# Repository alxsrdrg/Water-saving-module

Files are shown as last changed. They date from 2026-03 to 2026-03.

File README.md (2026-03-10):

# Water-saving-module
This is the data gatherer for a bigger project that will collect ambient data to save water while watering plants.
Hello, my name is Alexis. I am part of ACOIIN in Chile, and I designed this PCB to save water during the process of watering plants.

Most people don’t know how much water plants actually need to be watered efficiently, so I designed this small ATtiny85-based data gatherer to interface with other modules that will help water plants more efficiently—saving water, saving money, and helping the environment.

To use it you must upload the code to an ATtiny85 connect it to the pcb then upload the recivers code to an arduino with the reciver and watch the serial interface for the data this will be feeded into a algorthm tha will take the best moment for you to water the plants (WIP)

(BOM: https://docs.google.com/spreadsheets/d/1GQ0v_dI7ZX-GIWkH-TXZdrfXvmL1TNvHDqjCibz4H14/edit?usp=sharing)



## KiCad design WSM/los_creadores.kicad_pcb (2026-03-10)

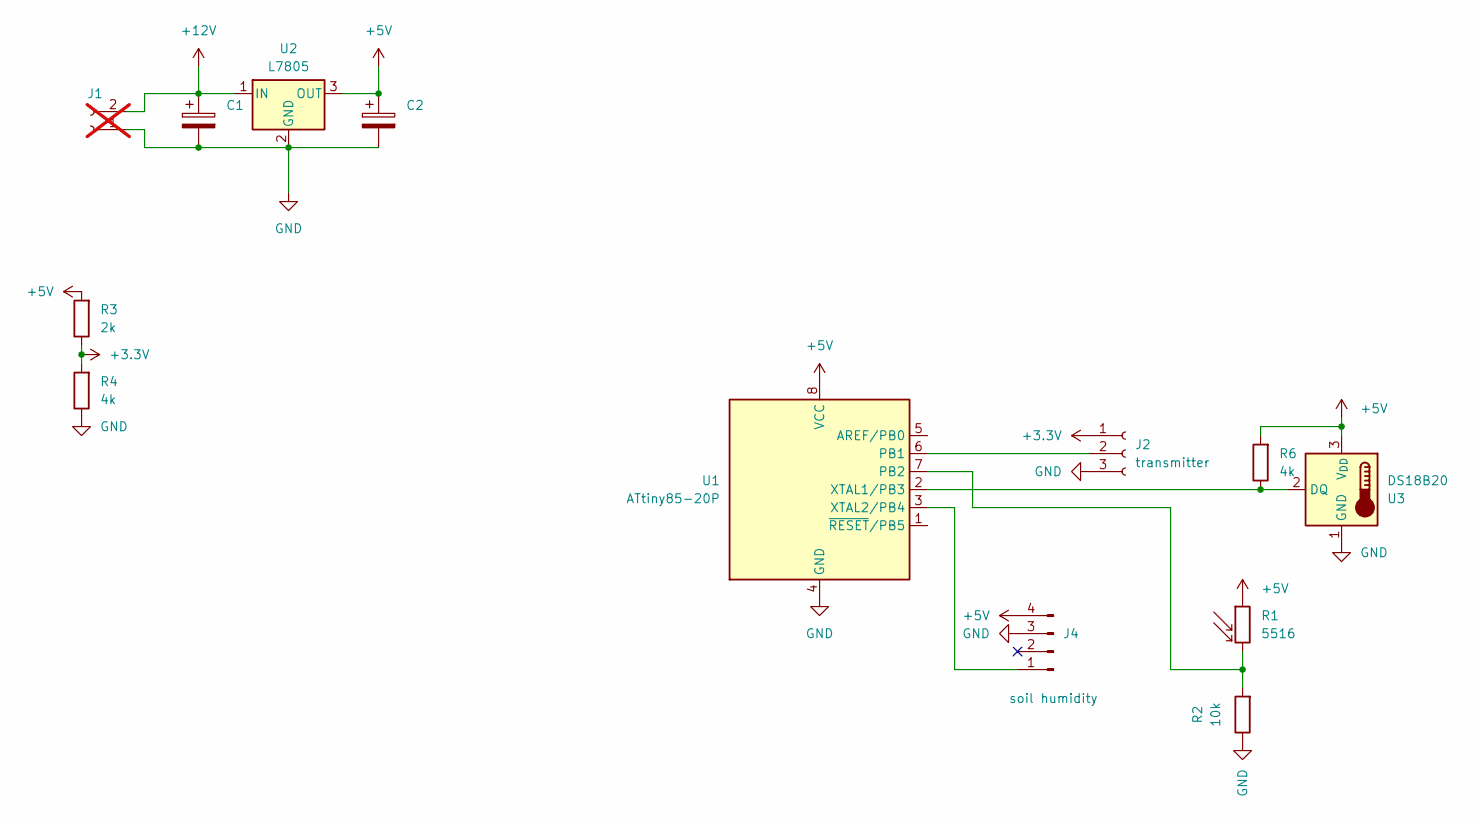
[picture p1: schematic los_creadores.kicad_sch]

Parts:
C1, C2: C_Polarized; CP_Radial_D4.0mm_P1.50mm
J1: Conn_01x02_Socket; PinHeader_1x02_P2.00mm_Vertical; not fitted
J2: transmitter; PinHeader_1x03_P2.00mm_Vertical
J4: soil humidity; PinHeader_1x04_P2.00mm_Vertical
R1: 5516; R_LDR_5.0x4.1mm_P3mm_Vertical
R2: 10k; R_Axial_DIN0207_L6.3mm_D2.5mm_P5.08mm_Vertical
R3: 2k; R_Axial_DIN0207_L6.3mm_D2.5mm_P5.08mm_Vertical
R4, R6: 4k; R_Axial_DIN0207_L6.3mm_D2.5mm_P5.08mm_Vertical
U1: ATtiny85-20P; DIP-8_W7.62mm
U2: L7805; TO-220-3_Horizontal_TabDown
U3: DS18B20; TO-92_Inline

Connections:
+3.3V: J2.1, R3.1, R4.2
+5V: C2.1, J4.4, R1.1, R3.2, R6.2, U1.8 (VCC), U2.3 (OUT), U3.3 (V_{DD})
+12V: C1.1, J1.2, U2.1 (IN)
GND: C1.2, C2.2, J1.1, J2.3, J4.3, R2.1, R4.1, U1.4 (GND), U2.2 (GND), U3.1 (GND)
unnamed: J2.2, U1.6 (PB1)
unnamed: J4.1, U1.3 (XTAL2/PB4)
unnamed: R1.2, R2.2, U1.7 (PB2)
unnamed: R6.1, U1.2 (XTAL1/PB3), U3.2 (DQ)

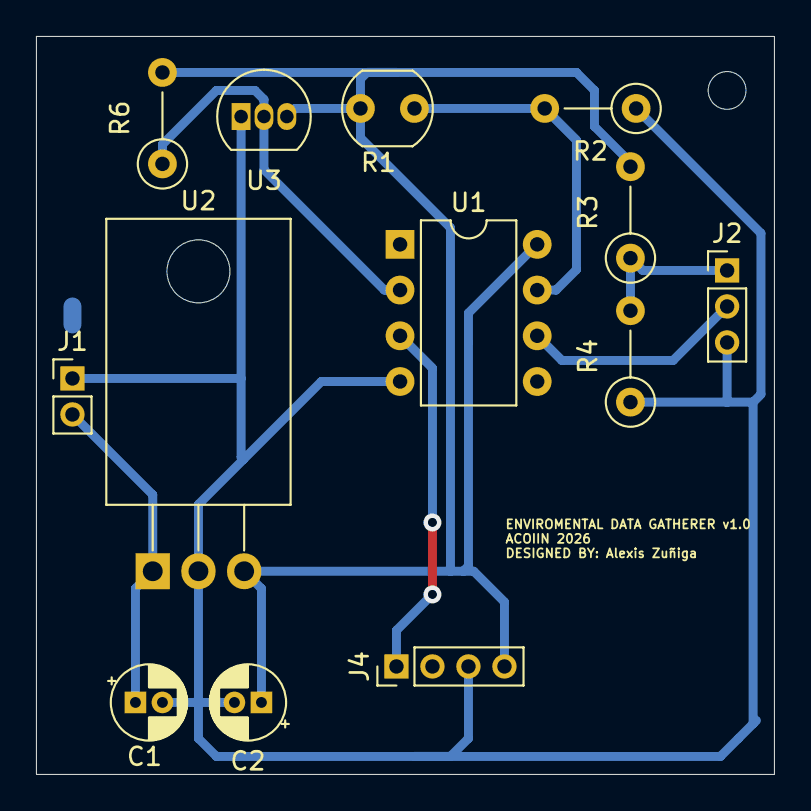
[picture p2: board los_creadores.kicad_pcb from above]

Board: 2 copper layers, 41.0 x 41.0 mm, 13 parts (0 on the bottom side), 8 nets.

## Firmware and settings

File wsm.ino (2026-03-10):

#include <Manchester.h>
#include <OneWire.h>
#include <DallasTemperature.h>
#include <avr/sleep.h>
#include <avr/wdt.h>

#define TX_PIN 1 
#define ONE_WIRE_BUS 3
#define LDR_PIN A1
#define SOIL_PIN A0

OneWire oneWire(ONE_WIRE_BUS);
DallasTemperature sensors(&oneWire);

volatile int watchdog_counter = 0;

ISR(WDT_vect) {
  watchdog_counter++;
}

void setup_watchdog() {
  MCUSR &= ~(1<<WDRF);
  WDTCR |= (1<<WDCE) | (1<<WDE);
  WDTCR = (1<<WDIE) | (1<<WDP3) | (1<<WDP0);
}

void enter_sleep() {
  set_sleep_mode(SLEEP_MODE_PWR_DOWN);
  sleep_enable();
  sleep_mode();
  sleep_disable(); 
}

void setup() {
  ADCSRA &= ~(1<<ADEN); 
  
  man.setupTransmit(TX_PIN, MAN_1200);
  sensors.begin();
  setup_watchdog();
}

void loop() {
  if (watchdog_counter >= 225 || watchdog_counter == 0) {
    watchdog_counter = 0;

    sensors.requestTemperatures();
    float tempC = sensors.getTempCByIndex(0);
    int16_t tempToSend = (int16_t)(tempC * 100);

    ADCSRA |= (1<<ADEN);
    delay(10);
    int16_t ldrToSend = analogRead(LDR_PIN);
    int16_t soilToSend = analogRead(SOIL_PIN);
    ADCSRA &= ~(1<<ADEN);

    for (int i = 0; i < 3; i++) {
      man.transmit(1);
      man.transmit(tempToSend);
      
      man.transmit(2);
      man.transmit(ldrToSend);
      
      man.transmit(3);
      man.transmit(soilToSend);
      
      delay(50); 
    }

    digitalWrite(TX_PIN, LOW);
  }

  enter_sleep();
}

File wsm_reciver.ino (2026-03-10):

#include <Manchester.h>

#define RX_PIN 4

uint8_t data_id = 0;

void setup() {
  Serial.begin(9600);
  man.setupReceive(RX_PIN, MAN_1200);
  man.beginReceive();
}

void loop() {
  if (man.receiveComplete()) {
    uint16_t receivedData = man.getMessage();
    man.beginReceive();

    if (data_id == 0) {
      if (receivedData == 1 || receivedData == 2 || receivedData == 3) {
        data_id = receivedData;
      }
    } else {
      if (data_id == 1) {
        Serial.print("T:");
        Serial.println(((int16_t)receivedData) / 100.0);
      } else if (data_id == 2) {
        Serial.print("L:");
        Serial.println(receivedData);
      } else if (data_id == 3) {
        Serial.print("S:");
        Serial.println(receivedData);
      }
      data_id = 0;
    }
  }
}
